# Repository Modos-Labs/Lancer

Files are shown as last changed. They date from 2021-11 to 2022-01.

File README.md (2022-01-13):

Lancer is the codename of our EPD laptop prototype.

# Specifications

The specification listed are preliminary and subject to change.

- SoC: Amlogic S922X (4x Cortex-A73 @ 2.2 GHz + 2x Cortex-A53 @ 2.0 GHz)
- RAM: 4GB DDR4 32bit
- SSD: User-replaceable M.2 SSD
- Network: 802.11n + BT4.0
- Screen: 13.3" 1600x1200 E-paper display via Caster EPDC (over MIPI DSI)
- Battery: Compatible with T4x battery
- Ports:
  - USB 2.0 Type-A Host x2
  - USB 2.0 Micro-B Device
  - USB Serial (Micro-B)
  - 10/100Mbps Ethernet
  - 3.5 mm Headphone Jack
  - 3.5 mm Line-In Jack
  - HDMI Output

# License

The hardware design is released under the CERN Open Source Hardware License strongly-reciprocal variant, CERN-OHL-S. A copy of the license is provided in the source repository. Additionally, user guide of the license is provided on ohwr.org.

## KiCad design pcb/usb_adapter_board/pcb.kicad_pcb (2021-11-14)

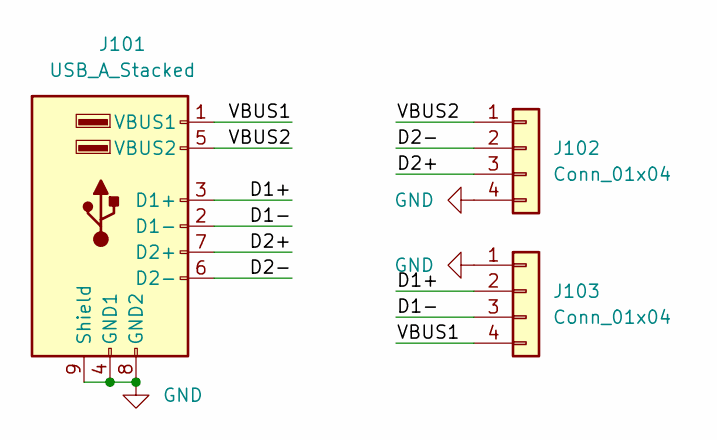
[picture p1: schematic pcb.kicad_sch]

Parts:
J101: USB_A_Stacked; USB_A_Wuerth_614008235023_Vertical_Stacked
J102, J103: Conn_01x04; PinHeader_1x04_P1.27mm_Horizontal_Alt

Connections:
/D1+: J101.3 (D1+), J103.2
/D1-: J101.2 (D1-), J103.3
/D2+: J101.7 (D2+), J102.3
/D2-: J101.6 (D2-), J102.2
/VBUS1: J101.1 (VBUS1), J103.4
/VBUS2: J101.5 (VBUS2), J102.1
GND: J101.4 (GND1), J101.8 (GND2), J101.9 (Shield), J102.4, J103.1

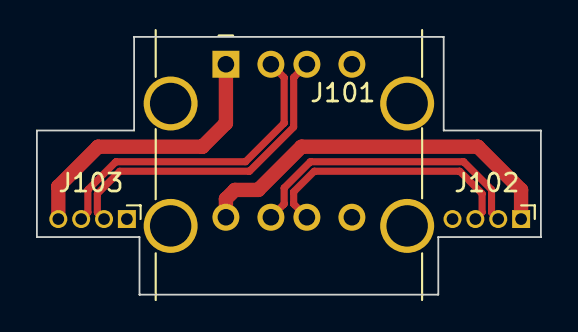
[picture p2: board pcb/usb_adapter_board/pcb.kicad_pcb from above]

Board: 2 copper layers, 28.0 x 14.3 mm, 3 parts (0 on the bottom side), 7 nets.

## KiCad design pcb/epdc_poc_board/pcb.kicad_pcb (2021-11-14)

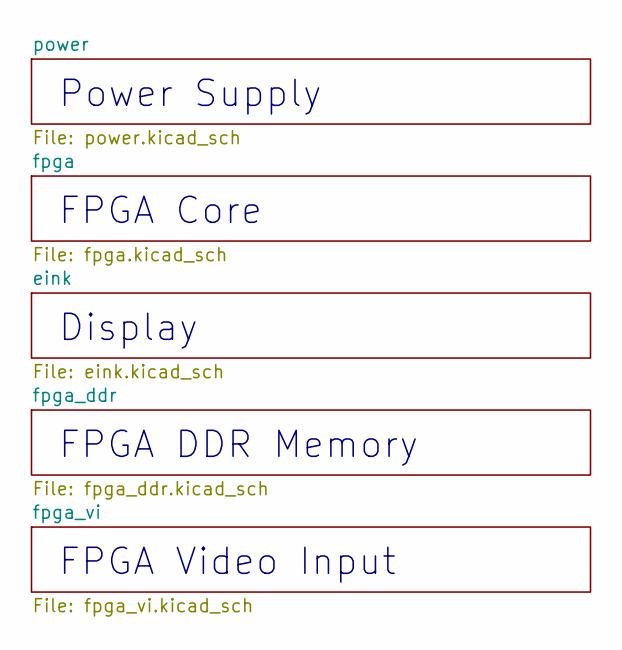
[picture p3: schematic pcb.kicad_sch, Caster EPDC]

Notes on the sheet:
Power Supply
FPGA Core
Display
FPGA DDR Memory
FPGA Video Input

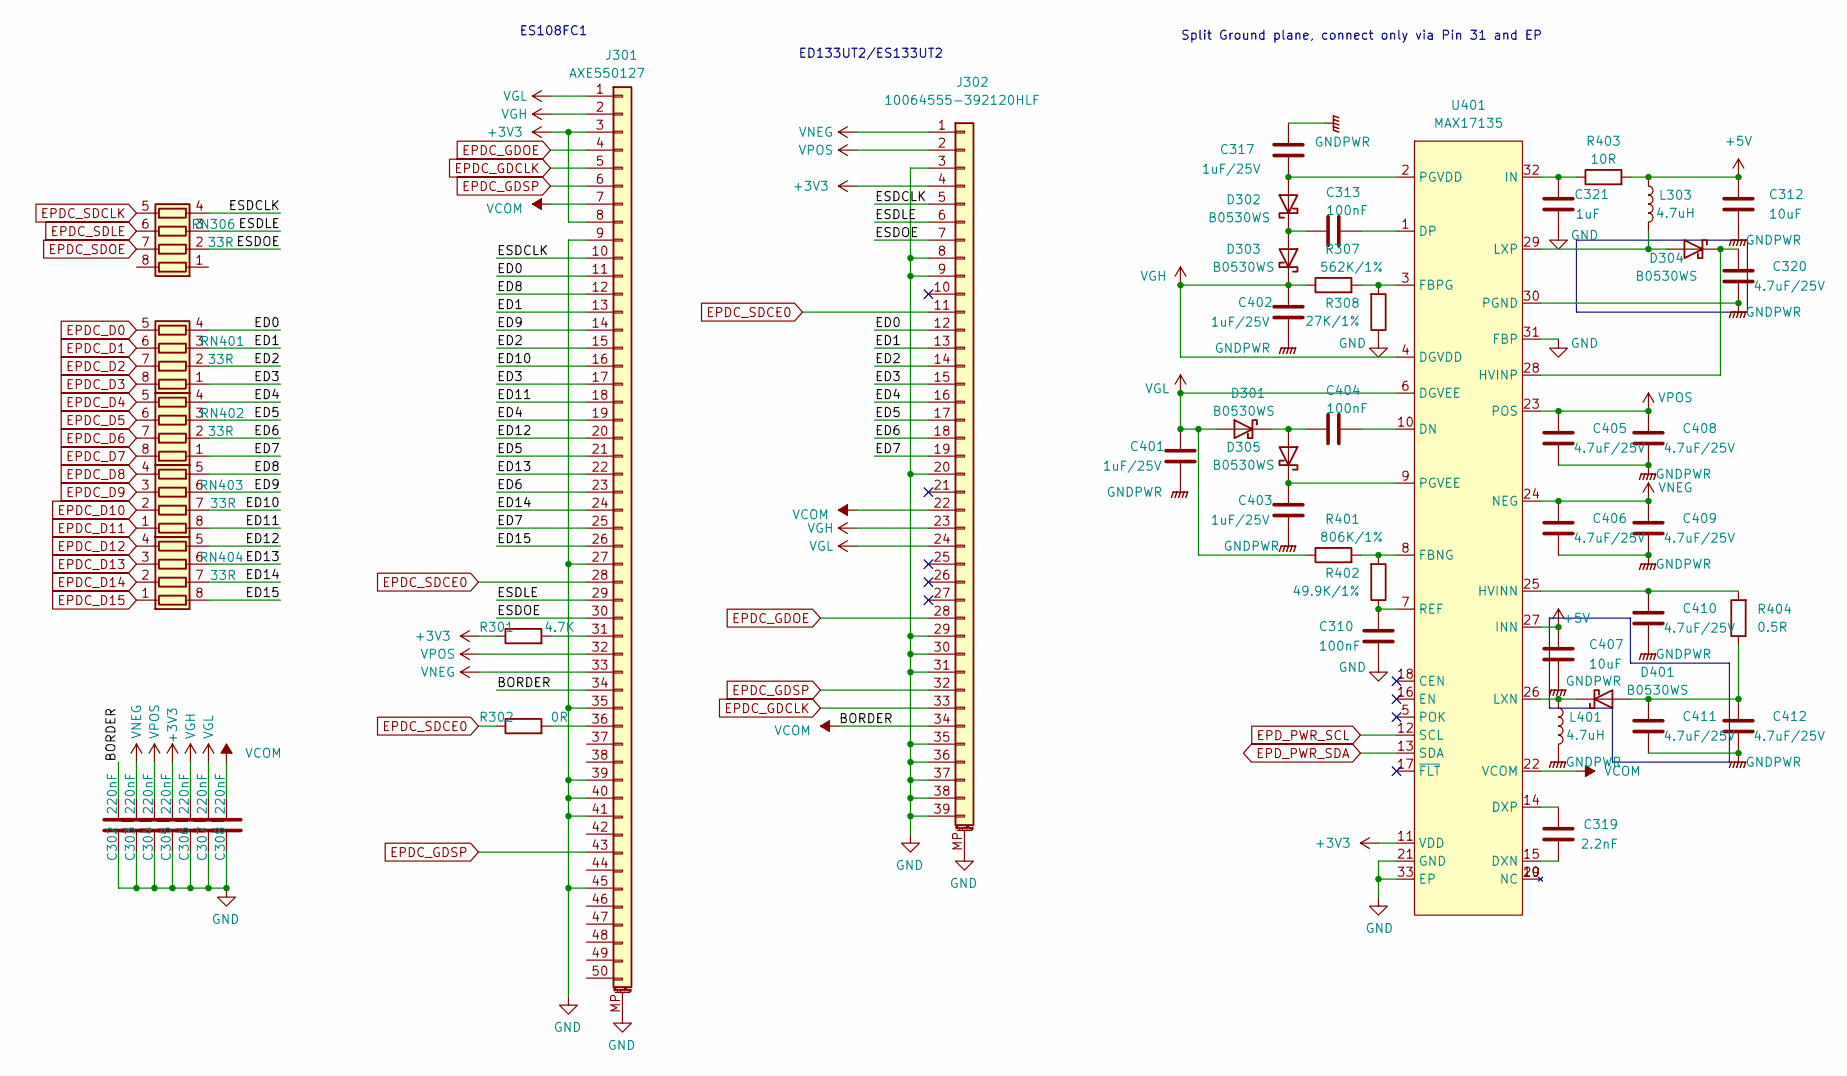
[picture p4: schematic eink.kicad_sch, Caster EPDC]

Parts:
C302, C303, C304, C305, C306, C307, C308: 220nF; C_0402_1005Metric; LCSC C880414
C310, C313, C404: 100nF; C_0402_1005Metric; LCSC C56392
C312, C407: 10uF; C_0603_1608Metric; LCSC C105490
C317, C401, C402, C403: 1uF/25V; C_0805_2012Metric; LCSC C111769
C319: 2.2nF; C_0402_1005Metric; LCSC C913886
C320, C405, C406, C408, C409, C410, C411, C412: 4.7uF/25V; C_0805_2012Metric; LCSC C105489
C321: 1uF; C_0402_1005Metric; LCSC C157353
D301, D302, D303, D304, D305, D401: B0530WS; D_SOD-323; LCSC C475612
J301: AXE550127
J302: 10064555-392120HLF; FCI_10064555-392120HLF; LCSC 609-10064555-392120HLFCT-ND
L303, L401: 4.7uH; L_1212; LCSC C340379
R301: 4.7K; R_0402_1005Metric; LCSC C105870
R302: 0R; R_0402_1005Metric; LCSC C60485
R307: 562K/1%; R_0402_1005Metric; LCSC C273337
R308: 27K/1%; R_0402_1005Metric; LCSC C138022
R401: 806K/1%; R_0402_1005Metric; LCSC C375495
R402: 49.9K/1%; R_0402_1005Metric; LCSC C137969
R403: 10R; R_0402_1005Metric; LCSC C137925
R404: 0.5R; R_0603_1608Metric; LCSC C45312
RN306, RN401, RN402, RN403, RN404: 33R; R_Array_Convex_4x0402; LCSC C148513
U401: MAX17135; QFN-32-1EP_5x5mm_P0.5mm_EP3.1x3.1mm_ThermalVias

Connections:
+3V3: C305.1, J301.3, J301.8, J302.4, R301.1, U401.11 (VDD); also elsewhere on the board
+5V: C312.2, C407.2, L303.1, R403.2, U401.27 (INN); also elsewhere on the board
/eink/ED0: J301.11, J302.12, RN401.4 (R4.1)
/eink/ED1: J301.13, J302.13, RN401.3 (R3.1)
/eink/ED2: J301.15, J302.14, RN401.2 (R2.1)
/eink/ED3: J301.17, J302.15, RN401.1 (R1.1)
/eink/ED4: J301.19, J302.16, RN402.4 (R4.1)
/eink/ED5: J301.21, J302.17, RN402.3 (R3.1)
/eink/ED6: J301.23, J302.18, RN402.2 (R2.1)
/eink/ED7: J301.25, J302.19, RN402.1 (R1.1)
/eink/ED8: J301.12, RN403.5 (R4.2)
/eink/ED9: J301.14, RN403.6 (R3.2)
/eink/ED10: J301.16, RN403.7 (R2.2)
/eink/ED11: J301.18, RN403.8 (R1.2)
/eink/ED12: J301.20, RN404.5 (R4.2)
/eink/ED13: J301.22, RN404.6 (R3.2)
/eink/ED14: J301.24, RN404.7 (R2.2)
/eink/ED15: J301.26, RN404.8 (R1.2)
/eink/ESDCLK: J301.10, J302.5, RN306.4 (R4.1)
/eink/ESDLE: J301.29, J302.6, RN306.3 (R3.1)
/eink/ESDOE: J301.30, J302.7, RN306.2 (R2.1)
EPDC_D0: RN401.5 (R4.2); also elsewhere on the board
EPDC_D1: RN401.6 (R3.2); also elsewhere on the board
EPDC_D2: RN401.7 (R2.2); also elsewhere on the board
EPDC_D3: RN401.8 (R1.2); also elsewhere on the board
EPDC_D4: RN402.5 (R4.2); also elsewhere on the board
EPDC_D5: RN402.6 (R3.2); also elsewhere on the board
EPDC_D6: RN402.7 (R2.2); also elsewhere on the board
EPDC_D7: RN402.8 (R1.2); also elsewhere on the board
EPDC_D8: RN403.4 (R4.1); also elsewhere on the board
EPDC_D9: RN403.3 (R3.1); also elsewhere on the board
EPDC_D10: RN403.2 (R2.1); also elsewhere on the board
EPDC_D11: RN403.1 (R1.1); also elsewhere on the board
EPDC_D12: RN404.4 (R4.1); also elsewhere on the board
EPDC_D13: RN404.3 (R3.1); also elsewhere on the board
EPDC_D14: RN404.2 (R2.1); also elsewhere on the board
EPDC_D15: RN404.1 (R1.1); also elsewhere on the board
EPDC_GDCLK: J301.5, J302.33; also elsewhere on the board
EPDC_GDOE: J301.4, J302.28; also elsewhere on the board
EPDC_GDSP: J301.6, J301.43, J302.32; also elsewhere on the board
EPDC_SDCE0: J301.28, J302.11, R302.1; also elsewhere on the board
EPDC_SDCLK: RN306.5 (R4.2); also elsewhere on the board
EPDC_SDLE: RN306.6 (R3.2); also elsewhere on the board
EPDC_SDOE: RN306.7 (R2.2); also elsewhere on the board
EPD_PWR_SCL: U401.12 (SCL); also elsewhere on the board
EPD_PWR_SDA: U401.13 (SDA); also elsewhere on the board
GND: C302.2, C303.2, C304.2, C305.2, C306.2, C307.2, C308.2, C310.1, C321.1, J301.9, J301.27, J301.35, J301.39, J301.40, J301.41, J301.45, J301.MP (MountPin), J302.3, J302.8, J302.9, J302.20, J302.29, J302.30, J302.31, J302.35, J302.36, J302.37, J302.38, J302.39, J302.MP (MountPin), R308.1, U401.21 (GND), U401.31 (FBP), U401.33 (EP); also elsewhere on the board
GNDPWR: C312.1, C317.2, C320.1, C401.1, C402.1, C403.1, C405.1, C406.1, C407.1, C408.1, C409.1, C410.1, C411.1, C412.1, L401.2, U401.30 (PGND)
unnamed: C310.2, R402.1, U401.7 (REF)
unnamed: C313.1, D302.1 (K), D303.2 (A)
unnamed: C313.2, U401.1 (DP)
unnamed: C317.1, D302.2 (A), U401.2 (PGVDD)
unnamed: C319.1, U401.15 (DXN)
unnamed: C319.2, U401.14 (DXP)
unnamed: C320.2, D304.1 (K), U401.28 (HVINP)
unnamed: C321.2, R403.1, U401.32 (IN)
unnamed: C403.2, D305.1 (K), U401.9 (PGVEE)
unnamed: C404.1, D301.1 (K), D305.2 (A)
unnamed: C404.2, U401.10 (DN)
unnamed: C410.2, R404.2, U401.25 (HVINN)
unnamed: C411.2, C412.2, D401.2 (A), R404.1
unnamed: D304.2 (A), L303.2, U401.29 (LXP)
unnamed: D401.1 (K), L401.1, U401.26 (LXN)
unnamed: J301.31, R301.2
unnamed: J301.36, R302.2
unnamed: R307.2, R308.2, U401.3 (FBPG)
unnamed: R401.2, R402.2, U401.8 (FBNG)
VCOM: C302.1, C308.1, J301.7, J301.34, J302.22, J302.34, U401.22 (VCOM)
VGH: C306.1, C402.2, D303.1 (K), J301.2, J302.23, R307.1, U401.4 (DGVDD)
VGL: C307.1, C401.2, D301.2 (A), J301.1, J302.24, R401.1, U401.6 (DGVEE)
VNEG: C303.1, C406.2, C409.2, J301.33, J302.1, U401.24 (NEG)
VPOS: C304.1, C405.2, C408.2, J301.32, J302.2, U401.23 (POS)

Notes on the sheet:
ES108FC1
ED133UT2/ES133UT2
Split Ground plane, connect only via Pin 31 and EP

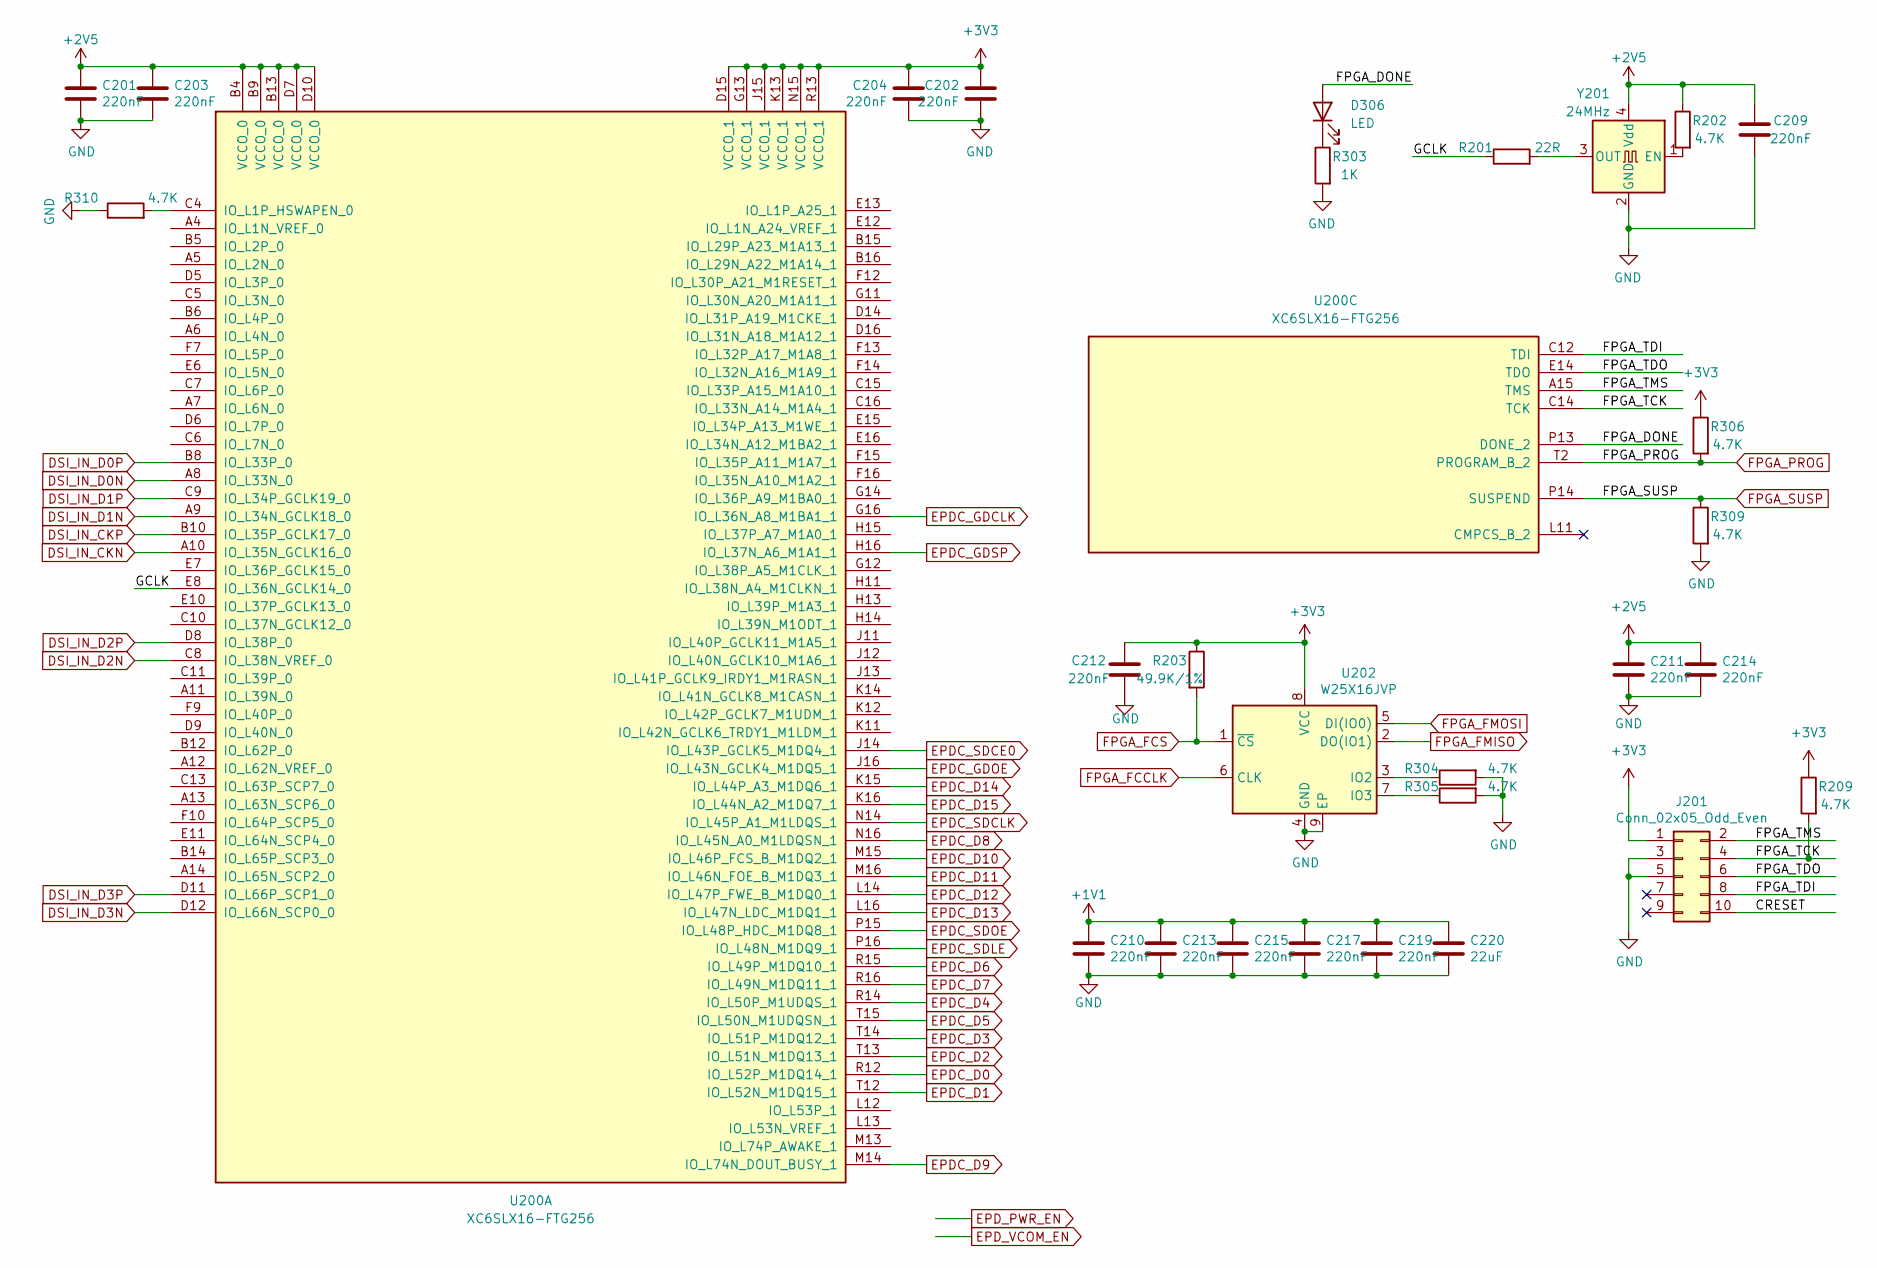
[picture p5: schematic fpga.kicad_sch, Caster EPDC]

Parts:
C201, C202, C203, C204, C209, C210, C211, C212, C213, C214, C215, C217, C219: 220nF; C_0402_1005Metric; LCSC C880414
C220: 22uF; C_0603_1608Metric; LCSC C94018
D306: LED; LED_0603_1608Metric; LCSC C90692
J201: Conn_02x05_Odd_Even; PinHeader_2x05_P1.27mm_Vertical_SMD
R201: 22R; R_0402_1005Metric; LCSC C93929
R202, R209, R304, R305, R306, R309, R310: 4.7K; R_0402_1005Metric; LCSC C105870
R203: 49.9K/1%; R_0402_1005Metric; LCSC C137969
R303: 1K; R_0402_1005Metric; LCSC C105637
U200: XC6SLX16-FTG256; BGA-256_14.0x14.0mm_Layout16x16_P0.8mm_Ball0.45mm_Pad0.32mm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; LCSC C39313
U202: W25X16JVP; WSON-8-1EP_6x5mm_P1.27mm_EP3.4x4.3mm; LCSC C571260
Y201: 24MHz; Oscillator_SMD_Abracon_ASE-4Pin_3.2x2.5mm; LCSC C252339

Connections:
+1V1: C210.1, C213.1, C215.1, C217.1, C219.1, C220.1; also elsewhere on the board
+2V5: C201.1, C203.1, C209.2, C211.1, C214.1, R202.1, U200.B4 (VCCO_0), U200.B9 (VCCO_0), U200.B13 (VCCO_0), U200.D7 (VCCO_0), U200.D10 (VCCO_0), Y201.4 (Vdd); also elsewhere on the board
+3V3: C202.1, C204.1, C212.2, J201.1, R203.1, R209.1, R306.1, U200.D15 (VCCO_1), U200.G13 (VCCO_1), U200.J15 (VCCO_1), U200.K13 (VCCO_1), U200.N15 (VCCO_1), U200.R13 (VCCO_1), U202.8 (VCC); also elsewhere on the board
/fpga/CRESET: J201.10
/fpga/FPGA_DONE: D306.2 (A), U200.P13 (DONE_2)
/fpga/FPGA_TCK: J201.4, R209.2, U200.C14 (TCK)
/fpga/FPGA_TDI: J201.8, U200.C12 (TDI)
/fpga/FPGA_TDO: J201.6, U200.E14 (TDO)
/fpga/FPGA_TMS: J201.2, U200.A15 (TMS)
/fpga/GCLK: R201.1, U200.E8 (IO_L36N_GCLK14_0)
DSI_IN_CKN: U200.A10 (IO_L35N_GCLK16_0); also elsewhere on the board
DSI_IN_CKP: U200.B10 (IO_L35P_GCLK17_0); also elsewhere on the board
DSI_IN_D0N: U200.A8 (IO_L33N_0); also elsewhere on the board
DSI_IN_D0P: U200.B8 (IO_L33P_0); also elsewhere on the board
DSI_IN_D1N: U200.A9 (IO_L34N_GCLK18_0); also elsewhere on the board
DSI_IN_D1P: U200.C9 (IO_L34P_GCLK19_0); also elsewhere on the board
DSI_IN_D2N: U200.C8 (IO_L38N_VREF_0); also elsewhere on the board
DSI_IN_D2P: U200.D8 (IO_L38P_0); also elsewhere on the board
DSI_IN_D3N: U200.D12 (IO_L66N_SCP0_0); also elsewhere on the board
DSI_IN_D3P: U200.D11 (IO_L66P_SCP1_0); also elsewhere on the board
EPDC_D0: U200.R12 (IO_L52P_M1DQ14_1); also elsewhere on the board
EPDC_D1: U200.T12 (IO_L52N_M1DQ15_1); also elsewhere on the board
EPDC_D2: U200.T13 (IO_L51N_M1DQ13_1); also elsewhere on the board
EPDC_D3: U200.T14 (IO_L51P_M1DQ12_1); also elsewhere on the board
EPDC_D4: U200.R14 (IO_L50P_M1UDQS_1); also elsewhere on the board
EPDC_D5: U200.T15 (IO_L50N_M1UDQSN_1); also elsewhere on the board
EPDC_D6: U200.R15 (IO_L49P_M1DQ10_1); also elsewhere on the board
EPDC_D7: U200.R16 (IO_L49N_M1DQ11_1); also elsewhere on the board
EPDC_D8: U200.N16 (IO_L45N_A0_M1LDQSN_1); also elsewhere on the board
EPDC_D9: U200.M14 (IO_L74N_DOUT_BUSY_1); also elsewhere on the board
EPDC_D10: U200.M15 (IO_L46P_FCS_B_M1DQ2_1); also elsewhere on the board
EPDC_D11: U200.M16 (IO_L46N_FOE_B_M1DQ3_1); also elsewhere on the board
EPDC_D12: U200.L14 (IO_L47P_FWE_B_M1DQ0_1); also elsewhere on the board
EPDC_D13: U200.L16 (IO_L47N_LDC_M1DQ1_1); also elsewhere on the board
EPDC_D14: U200.K15 (IO_L44P_A3_M1DQ6_1); also elsewhere on the board
EPDC_D15: U200.K16 (IO_L44N_A2_M1DQ7_1); also elsewhere on the board
EPDC_GDCLK: U200.G16 (IO_L36N_A8_M1BA1_1); also elsewhere on the board
EPDC_GDOE: U200.J16 (IO_L43N_GCLK4_M1DQ5_1); also elsewhere on the board
EPDC_GDSP: U200.H16 (IO_L37N_A6_M1A1_1); also elsewhere on the board
EPDC_SDCE0: U200.J14 (IO_L43P_GCLK5_M1DQ4_1); also elsewhere on the board
EPDC_SDCLK: U200.N14 (IO_L45P_A1_M1LDQS_1); also elsewhere on the board
EPDC_SDLE: U200.P16 (IO_L48N_M1DQ9_1); also elsewhere on the board
EPDC_SDOE: U200.P15 (IO_L48P_HDC_M1DQ8_1); also elsewhere on the board
FPGA_FCCLK: U202.6 (CLK); also elsewhere on the board
FPGA_FCS: R203.2, U202.1 (~CS); also elsewhere on the board
FPGA_FMISO: U202.2 (DO(IO1)); also elsewhere on the board
FPGA_FMOSI: U202.5 (DI(IO0)); also elsewhere on the board
FPGA_PROG: R306.2, U200.T2 (PROGRAM_B_2); also elsewhere on the board
FPGA_SUSP: R309.1, U200.P14 (SUSPEND); also elsewhere on the board
GND: C201.2, C202.2, C203.2, C204.2, C209.1, C210.2, C211.2, C212.1, C213.2, C214.2, C215.2, C217.2, C219.2, C220.2, J201.3, J201.5, R303.2, R304.2, R305.2, R309.2, R310.1, U202.4 (GND), U202.9 (EP), Y201.2 (GND); also elsewhere on the board
unnamed: D306.1 (K), R303.1
unnamed: R201.2, Y201.3 (OUT)
unnamed: R202.2, Y201.1 (EN)
unnamed: R304.1, U202.3 (IO2)
unnamed: R305.1, U202.7 (IO3)
unnamed: R310.2, U200.C4 (IO_L1P_HSWAPEN_0)

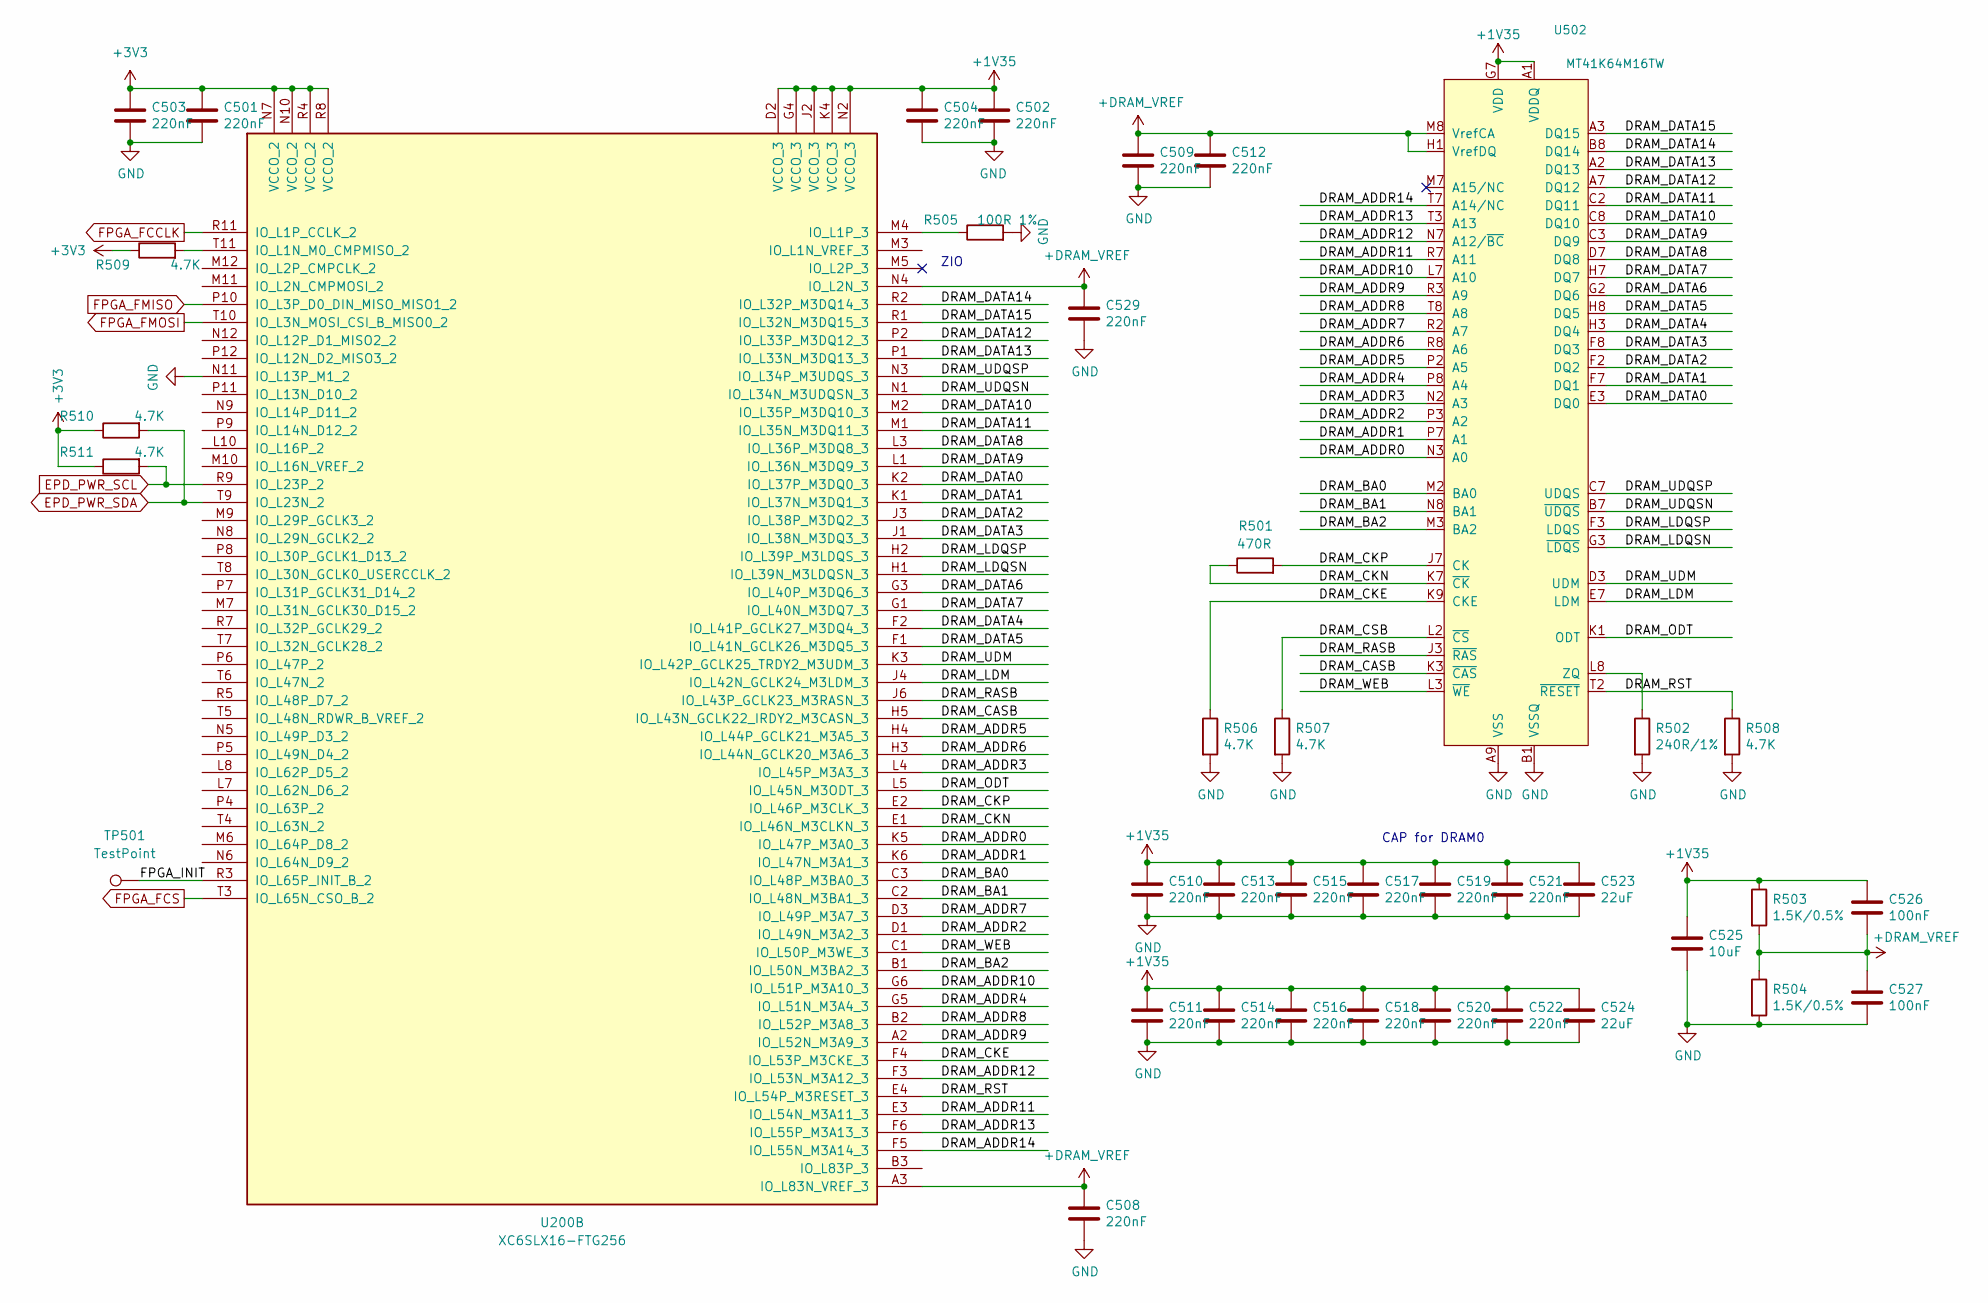
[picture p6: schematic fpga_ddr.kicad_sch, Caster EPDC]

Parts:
C501, C502, C503, C504, C508, C509, C510, C511, C512, C513, C514, C515, C516, C517, C518, C519, C520, C521, C522, C529: 220nF; C_0402_1005Metric; LCSC C880414
C523, C524: 22uF; C_0603_1608Metric; LCSC C94018
C525: 10uF; C_0603_1608Metric; LCSC C105490
C526, C527: 100nF; C_0402_1005Metric; LCSC C56392
R501: 470R; R_0402_1005Metric; LCSC C114877
R502: 240R/1%; R_0402_1005Metric; LCSC C114755
R503, R504: 1.5K/0.5%; R_0402_1005Metric; LCSC C226693
R505: 100R 1%; R_0402_1005Metric; LCSC C106232
R506, R507, R508, R509, R510, R511: 4.7K; R_0402_1005Metric; LCSC C105870
TP501: TestPoint; TestPoint_Pad_D1.0mm
U200: XC6SLX16-FTG256; BGA-256_14.0x14.0mm_Layout16x16_P0.8mm_Ball0.45mm_Pad0.32mm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; LCSC C39313
U502: MT41K64M16TW; BGA-96_9.0x14.0mm_P0.8mm; LCSC C524855

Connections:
+1V35: C502.1, C504.1, C510.1, C511.1, C513.1, C514.1, C515.1, C516.1, C517.1, C518.1, C519.1, C520.1, C521.1, C522.1, C523.1, C524.1, C525.1, C526.1, R503.1, U200.D2 (VCCO_3), U200.G4 (VCCO_3), U200.J2 (VCCO_3), U200.K4 (VCCO_3), U200.N2 (VCCO_3), U502.A1 (VDDQ), U502.A8 (VDDQ), U502.B2 (VDD), U502.C1 (VDDQ), U502.C9 (VDDQ), U502.D2 (VDDQ), U502.D9 (VDD), U502.E9 (VDDQ), U502.F1 (VDDQ), U502.G7 (VDD), U502.H2 (VDDQ), U502.H9 (VDDQ), U502.K2 (VDD), U502.K8 (VDD), U502.N1 (VDD), U502.N9 (VDD), U502.R1 (VDD), U502.R9 (VDD); also elsewhere on the board
+3V3: C501.1, C503.1, R509.1, R510.1, R511.1, U200.N7 (VCCO_2), U200.N10 (VCCO_2), U200.R4 (VCCO_2), U200.R8 (VCCO_2); also elsewhere on the board
+DRAM_VREF: C508.1, C509.1, C512.1, C526.2, C527.1, C529.1, R503.2, R504.1, U200.A3 (IO_L83N_VREF_3), U200.N4 (IO_L2N_3), U502.H1 (VrefDQ), U502.M8 (VrefCA)
/fpga_ddr/DRAM_ADDR0: U200.K5 (IO_L47P_M3A0_3), U502.N3 (A0)
/fpga_ddr/DRAM_ADDR1: U200.K6 (IO_L47N_M3A1_3), U502.P7 (A1)
/fpga_ddr/DRAM_ADDR2: U200.D1 (IO_L49N_M3A2_3), U502.P3 (A2)
/fpga_ddr/DRAM_ADDR3: U200.L4 (IO_L45P_M3A3_3), U502.N2 (A3)
/fpga_ddr/DRAM_ADDR4: U200.G5 (IO_L51N_M3A4_3), U502.P8 (A4)
/fpga_ddr/DRAM_ADDR5: U200.H4 (IO_L44P_GCLK21_M3A5_3), U502.P2 (A5)
/fpga_ddr/DRAM_ADDR6: U200.H3 (IO_L44N_GCLK20_M3A6_3), U502.R8 (A6)
/fpga_ddr/DRAM_ADDR7: U200.D3 (IO_L49P_M3A7_3), U502.R2 (A7)
/fpga_ddr/DRAM_ADDR8: U200.B2 (IO_L52P_M3A8_3), U502.T8 (A8)
/fpga_ddr/DRAM_ADDR9: U200.A2 (IO_L52N_M3A9_3), U502.R3 (A9)
/fpga_ddr/DRAM_ADDR10: U200.G6 (IO_L51P_M3A10_3), U502.L7 (A10)
/fpga_ddr/DRAM_ADDR11: U200.E3 (IO_L54N_M3A11_3), U502.R7 (A11)
/fpga_ddr/DRAM_ADDR12: U200.F3 (IO_L53N_M3A12_3), U502.N7 (A12/~BC)
/fpga_ddr/DRAM_ADDR13: U200.F6 (IO_L55P_M3A13_3), U502.T3 (A13)
/fpga_ddr/DRAM_ADDR14: U200.F5 (IO_L55N_M3A14_3), U502.T7 (A14/NC)
/fpga_ddr/DRAM_BA0: U200.C3 (IO_L48P_M3BA0_3), U502.M2 (BA0)
/fpga_ddr/DRAM_BA1: U200.C2 (IO_L48N_M3BA1_3), U502.N8 (BA1)
/fpga_ddr/DRAM_BA2: U200.B1 (IO_L50N_M3BA2_3), U502.M3 (BA2)
/fpga_ddr/DRAM_CASB: U200.H5 (IO_L43N_GCLK22_IRDY2_M3CASN_3), U502.K3 (~CAS)
/fpga_ddr/DRAM_CKE: R506.1, U200.F4 (IO_L53P_M3CKE_3), U502.K9 (CKE)
/fpga_ddr/DRAM_CKN: R501.1, U200.E1 (IO_L46N_M3CLKN_3), U502.K7 (~CK)
/fpga_ddr/DRAM_CKP: R501.2, U200.E2 (IO_L46P_M3CLK_3), U502.J7 (CK)
/fpga_ddr/DRAM_CSB: R507.1, U502.L2 (~CS)
/fpga_ddr/DRAM_DATA0: U200.K2 (IO_L37P_M3DQ0_3), U502.E3 (DQ0)
/fpga_ddr/DRAM_DATA1: U200.K1 (IO_L37N_M3DQ1_3), U502.F7 (DQ1)
/fpga_ddr/DRAM_DATA2: U200.J3 (IO_L38P_M3DQ2_3), U502.F2 (DQ2)
/fpga_ddr/DRAM_DATA3: U200.J1 (IO_L38N_M3DQ3_3), U502.F8 (DQ3)
/fpga_ddr/DRAM_DATA4: U200.F2 (IO_L41P_GCLK27_M3DQ4_3), U502.H3 (DQ4)
/fpga_ddr/DRAM_DATA5: U200.F1 (IO_L41N_GCLK26_M3DQ5_3), U502.H8 (DQ5)
/fpga_ddr/DRAM_DATA6: U200.G3 (IO_L40P_M3DQ6_3), U502.G2 (DQ6)
/fpga_ddr/DRAM_DATA7: U200.G1 (IO_L40N_M3DQ7_3), U502.H7 (DQ7)
/fpga_ddr/DRAM_DATA8: U200.L3 (IO_L36P_M3DQ8_3), U502.D7 (DQ8)
/fpga_ddr/DRAM_DATA9: U200.L1 (IO_L36N_M3DQ9_3), U502.C3 (DQ9)
/fpga_ddr/DRAM_DATA10: U200.M2 (IO_L35P_M3DQ10_3), U502.C8 (DQ10)
/fpga_ddr/DRAM_DATA11: U200.M1 (IO_L35N_M3DQ11_3), U502.C2 (DQ11)
/fpga_ddr/DRAM_DATA12: U200.P2 (IO_L33P_M3DQ12_3), U502.A7 (DQ12)
/fpga_ddr/DRAM_DATA13: U200.P1 (IO_L33N_M3DQ13_3), U502.A2 (DQ13)
/fpga_ddr/DRAM_DATA14: U200.R2 (IO_L32P_M3DQ14_3), U502.B8 (DQ14)
/fpga_ddr/DRAM_DATA15: U200.R1 (IO_L32N_M3DQ15_3), U502.A3 (DQ15)
/fpga_ddr/DRAM_LDM: U200.J4 (IO_L42N_GCLK24_M3LDM_3), U502.E7 (LDM)
/fpga_ddr/DRAM_LDQSN: U200.H1 (IO_L39N_M3LDQSN_3), U502.G3 (~LDQS)
/fpga_ddr/DRAM_LDQSP: U200.H2 (IO_L39P_M3LDQS_3), U502.F3 (LDQS)
/fpga_ddr/DRAM_ODT: U200.L5 (IO_L45N_M3ODT_3), U502.K1 (ODT)
/fpga_ddr/DRAM_RASB: U200.J6 (IO_L43P_GCLK23_M3RASN_3), U502.J3 (~RAS)
/fpga_ddr/DRAM_RST: R508.1, U200.E4 (IO_L54P_M3RESET_3), U502.T2 (~RESET)
/fpga_ddr/DRAM_UDM: U200.K3 (IO_L42P_GCLK25_TRDY2_M3UDM_3), U502.D3 (UDM)
/fpga_ddr/DRAM_UDQSN: U200.N1 (IO_L34N_M3UDQSN_3), U502.B7 (~UDQS)
/fpga_ddr/DRAM_UDQSP: U200.N3 (IO_L34P_M3UDQS_3), U502.C7 (UDQS)
/fpga_ddr/DRAM_WEB: U200.C1 (IO_L50P_M3WE_3), U502.L3 (~WE)
/fpga_ddr/FPGA_INIT: TP501.1, U200.R3 (IO_L65P_INIT_B_2)
EPD_PWR_SCL: R511.2, U200.R9 (IO_L23P_2); also elsewhere on the board
EPD_PWR_SDA: R510.2, U200.T9 (IO_L23N_2); also elsewhere on the board
FPGA_FCCLK: U200.R11 (IO_L1P_CCLK_2); also elsewhere on the board
FPGA_FCS: U200.T3 (IO_L65N_CSO_B_2); also elsewhere on the board
FPGA_FMISO: U200.P10 (IO_L3P_D0_DIN_MISO_MISO1_2); also elsewhere on the board
FPGA_FMOSI: U200.T10 (IO_L3N_MOSI_CSI_B_MISO0_2); also elsewhere on the board
GND: C501.2, C502.2, C503.2, C504.2, C508.2, C509.2, C510.2, C511.2, C512.2, C513.2, C514.2, C515.2, C516.2, C517.2, C518.2, C519.2, C520.2, C521.2, C522.2, C523.2, C524.2, C525.2, C527.2, C529.2, R502.2, R504.2, R505.2, R506.2, R507.2, R508.2, U200.N11 (IO_L13P_M1_2), U502.A9 (VSS), U502.B1 (VSSQ), U502.B3 (VSS), U502.B9 (VSSQ), U502.D1 (VSSQ), U502.D8 (VSSQ), U502.E1 (VSS), U502.E2 (VSSQ), U502.E8 (VSSQ), U502.F9 (VSSQ), U502.G1 (VSSQ), U502.G8 (VSS), U502.G9 (VSSQ), U502.J2 (VSS), U502.J8 (VSS), U502.M1 (VSS), U502.M9 (VSS), U502.P1 (VSS), U502.P9 (VSS), U502.T1 (VSS), U502.T9 (VSS); also elsewhere on the board
unnamed: R502.1, U502.L8 (ZQ)
unnamed: R505.1, U200.M4 (IO_L1P_3)
unnamed: R509.2, U200.T11 (IO_L1N_M0_CMPMISO_2)

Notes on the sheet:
ZIO
CAP for DRAM0

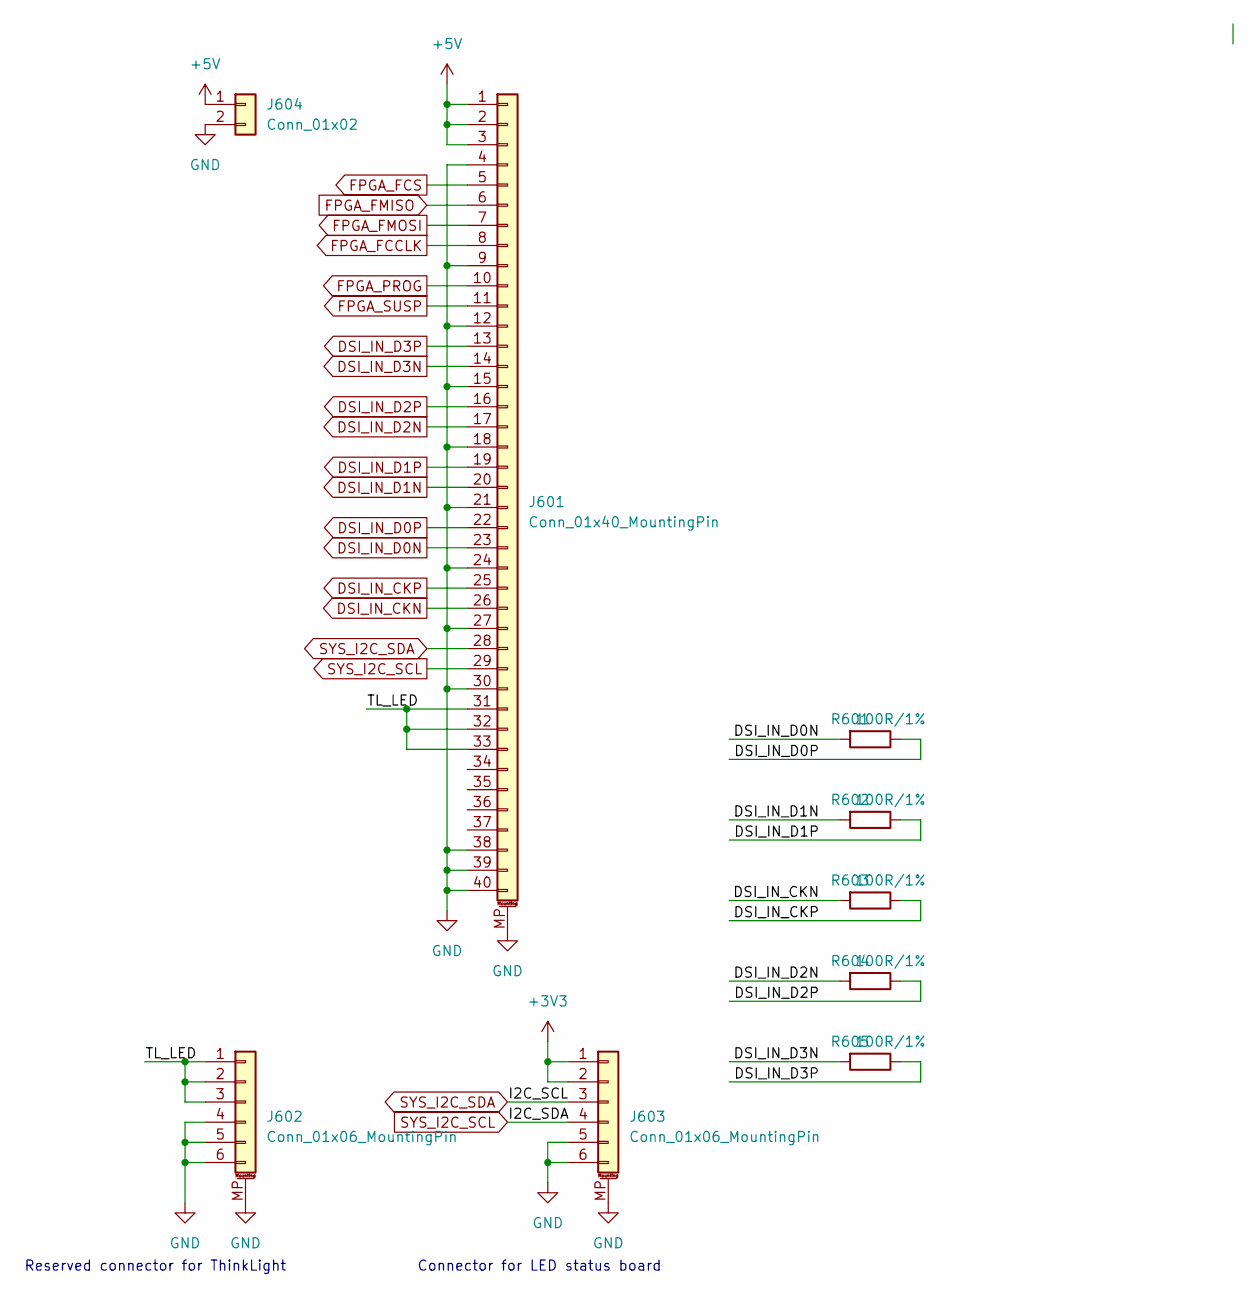
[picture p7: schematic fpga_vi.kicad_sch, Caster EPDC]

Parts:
J601: Conn_01x40_MountingPin; Hirose_FH12-40S-0.5SH_1x40-1MP_P0.50mm_Horizontal; LCSC C376071
J602, J603: Conn_01x06_MountingPin; Hirose_FH12-6S-0.5SH_1x06-1MP_P0.50mm_Horizontal; LCSC C283139
J604: Conn_01x02; PinHeader_1x02_P2.54mm_Vertical
R601, R602, R603, R604, R605: 100R/1%; R_0402_1005Metric; LCSC C106232

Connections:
+3V3: J603.1, J603.2; also elsewhere on the board
+5V: J601.1, J601.2, J601.3, J604.1; also elsewhere on the board
/fpga_vi/TL_LED: J601.31, J601.32, J601.33, J602.1, J602.2, J602.3
DSI_IN_CKN: J601.26, R603.2; also elsewhere on the board
DSI_IN_CKP: J601.25, R603.1; also elsewhere on the board
DSI_IN_D0N: J601.23, R601.2; also elsewhere on the board
DSI_IN_D0P: J601.22, R601.1; also elsewhere on the board
DSI_IN_D1N: J601.20, R602.2; also elsewhere on the board
DSI_IN_D1P: J601.19, R602.1; also elsewhere on the board
DSI_IN_D2N: J601.17, R604.2; also elsewhere on the board
DSI_IN_D2P: J601.16, R604.1; also elsewhere on the board
DSI_IN_D3N: J601.14, R605.2; also elsewhere on the board
DSI_IN_D3P: J601.13, R605.1; also elsewhere on the board
FPGA_FCCLK: J601.8; also elsewhere on the board
FPGA_FCS: J601.5; also elsewhere on the board
FPGA_FMISO: J601.6; also elsewhere on the board
FPGA_FMOSI: J601.7; also elsewhere on the board
FPGA_PROG: J601.10; also elsewhere on the board
FPGA_SUSP: J601.11; also elsewhere on the board
GND: J601.4, J601.9, J601.12, J601.15, J601.18, J601.21, J601.24, J601.27, J601.30, J601.38, J601.39, J601.40, J601.MP (MountPin), J602.4, J602.5, J602.6, J602.MP (MountPin), J603.5, J603.6, J603.MP (MountPin), J604.2; also elsewhere on the board
SYS_I2C_SCL: J601.29, J603.4
SYS_I2C_SDA: J601.28, J603.3

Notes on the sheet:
Reserved connector for ThinkLight
Connector for LED status board

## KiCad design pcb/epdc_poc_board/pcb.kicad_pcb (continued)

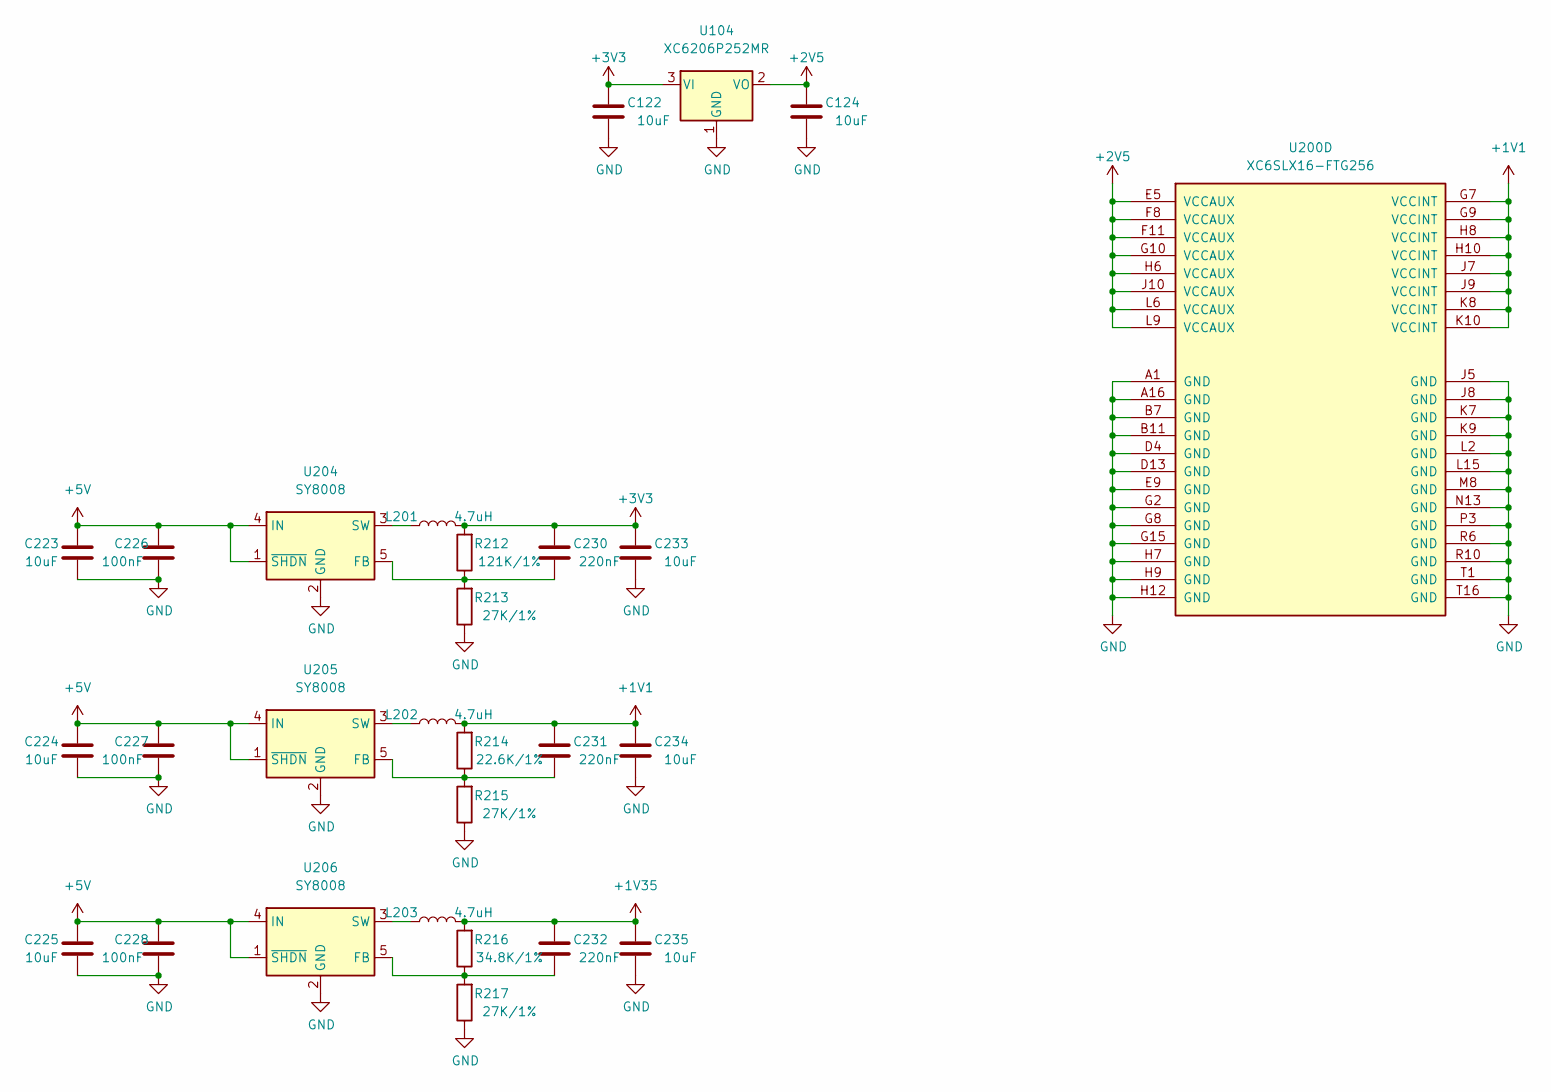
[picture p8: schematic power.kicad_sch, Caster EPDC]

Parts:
C122, C124, C223, C224, C225, C233, C234, C235: 10uF; C_0603_1608Metric; LCSC C105490
C226, C227, C228: 100nF; C_0402_1005Metric; LCSC C56392
C230, C231, C232: 220nF; C_0402_1005Metric; LCSC C880414
L201, L202, L203: 4.7uH; L_1212; LCSC C340379
R212: 121K/1%; R_0402_1005Metric; LCSC C112303
R213, R215, R217: 27K/1%; R_0402_1005Metric; LCSC C138022
R214: 22.6K/1%; R_0402_1005Metric; LCSC C477674
R216: 34.8K/1%; R_0402_1005Metric; LCSC C327350
U104: XC6206P252MR; SOT-23; LCSC C15906
U200: XC6SLX16-FTG256; BGA-256_14.0x14.0mm_Layout16x16_P0.8mm_Ball0.45mm_Pad0.32mm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; LCSC C39313
U204, U205, U206: SY8008; TSOT-23-5; LCSC C82161

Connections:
+1V1: C231.2, C234.2, L202.2, R214.2, U200.G7 (VCCINT), U200.G9 (VCCINT), U200.H8 (VCCINT), U200.H10 (VCCINT), U200.J7 (VCCINT), U200.J9 (VCCINT), U200.K8 (VCCINT), U200.K10 (VCCINT); also elsewhere on the board
+1V35: C232.2, C235.2, L203.2, R216.2; also elsewhere on the board
+2V5: C124.2, U104.2 (VO), U200.E5 (VCCAUX), U200.F8 (VCCAUX), U200.F11 (VCCAUX), U200.G10 (VCCAUX), U200.H6 (VCCAUX), U200.J10 (VCCAUX), U200.L6 (VCCAUX), U200.L9 (VCCAUX); also elsewhere on the board
+3V3: C122.2, C230.2, C233.2, L201.2, R212.2, U104.3 (VI); also elsewhere on the board
+5V: C223.2, C224.2, C225.2, C226.2, C227.2, C228.2, U204.1 (~SHDN), U204.4 (IN), U205.1 (~SHDN), U205.4 (IN), U206.1 (~SHDN), U206.4 (IN); also elsewhere on the board
GND: C122.1, C124.1, C223.1, C224.1, C225.1, C226.1, C227.1, C228.1, C233.1, C234.1, C235.1, R213.1, R215.1, R217.1, U104.1 (GND), U200.A1 (GND), U200.A16 (GND), U200.B7 (GND), U200.B11 (GND), U200.D4 (GND), U200.D13 (GND), U200.E9 (GND), U200.G2 (GND), U200.G8 (GND), U200.G15 (GND), U200.H7 (GND), U200.H9 (GND), U200.H12 (GND), U200.J5 (GND), U200.J8 (GND), U200.K7 (GND), U200.K9 (GND), U200.L2 (GND), U200.L15 (GND), U200.M8 (GND), U200.N13 (GND), U200.P3 (GND), U200.R6 (GND), U200.R10 (GND), U200.T1 (GND), U200.T16 (GND), U204.2 (GND), U205.2 (GND), U206.2 (GND); also elsewhere on the board
unnamed: C230.1, R212.1, R213.2, U204.5 (FB)
unnamed: C231.1, R214.1, R215.2, U205.5 (FB)
unnamed: C232.1, R216.1, R217.2, U206.5 (FB)
unnamed: L201.1, U204.3 (SW)
unnamed: L202.1, U205.3 (SW)
unnamed: L203.1, U206.3 (SW)

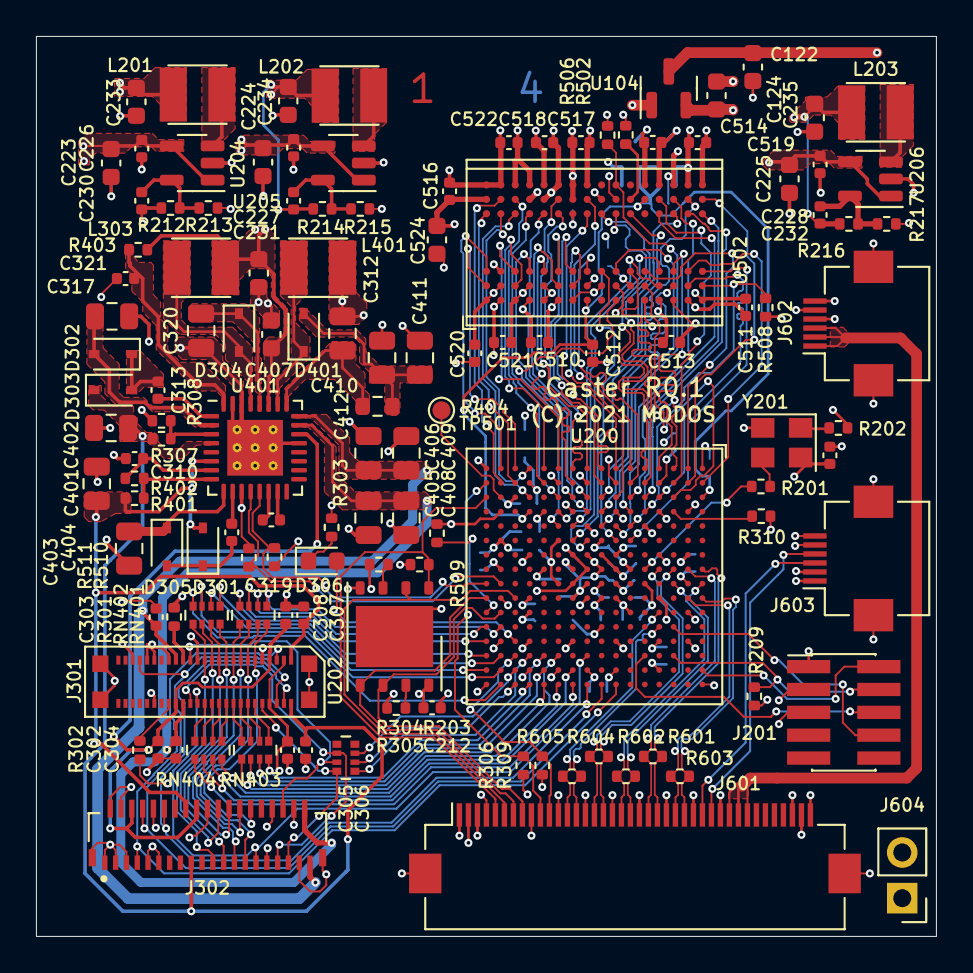
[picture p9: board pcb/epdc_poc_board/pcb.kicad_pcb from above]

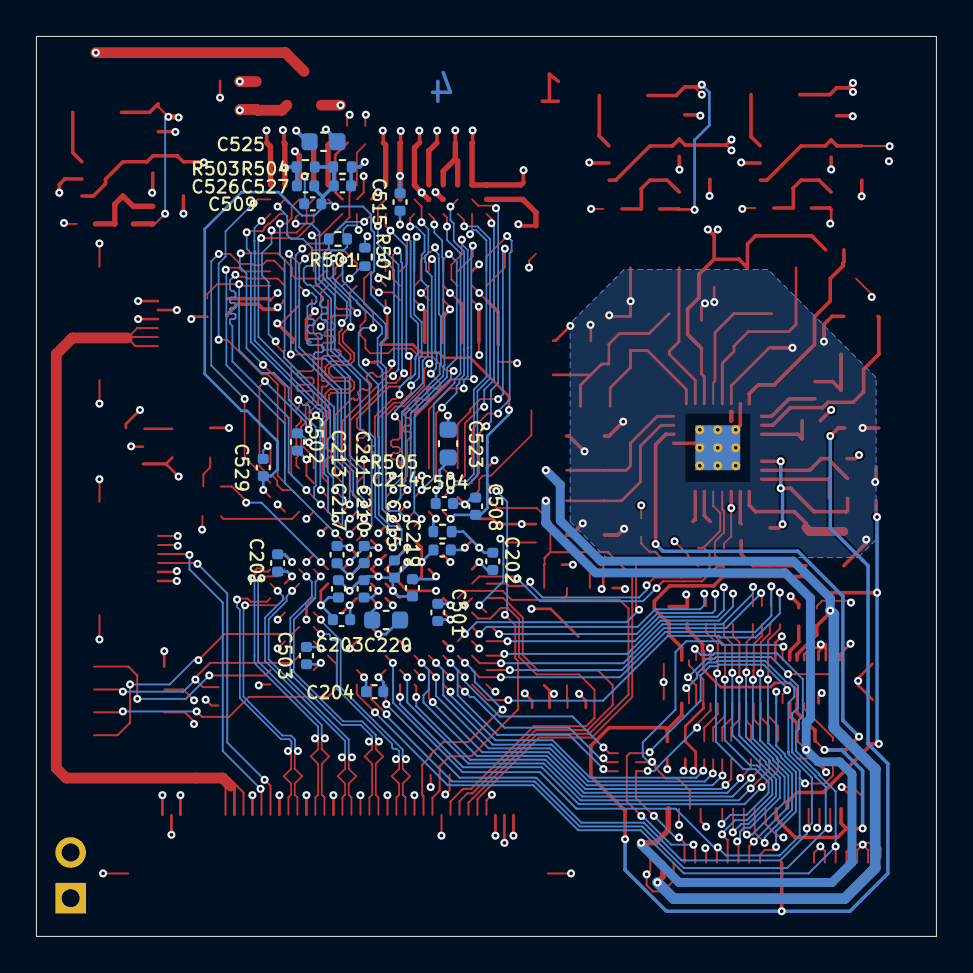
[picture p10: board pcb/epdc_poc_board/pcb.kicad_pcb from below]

Board: 4 copper layers, 50.0 x 50.0 mm, 153 parts (29 on the bottom side), 166 nets.

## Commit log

2021-10-10 pcb: move motherboard to a new directory; working on epdc poc board
    [eink.kicad_sch, fpga.kicad_sch, fpga_ddr.kicad_sch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]
2021-10-17 - wip epdc poc board, going to remove vga input
    [eink.kicad_sch, fpga.kicad_sch, fpga_ddr.kicad_sch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]
2021-10-24 pcb: switch to s6 for epdc board
    [eink.kicad_sch, fpga.kicad_sch, fpga_ddr.kicad_sch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]
2021-10-31 pcb: preliminary r0p1 schematics
    [audio.kicad_sch, cpu.kicad_sch, ddr.kicad_sch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]
2021-11-04 pcb: initial placement for mb
    [audio.kicad_sch, cpu.kicad_sch, ec.kicad_sch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]
2021-11-07 pcb: r0.1 mb routing done
    [audio.kicad_sch, cpu.kicad_sch, ec.kicad_sch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]
2021-11-14 pcb: mb r0.1, caster r0.1 freeze
    [audio.kicad_sch, cpu.kicad_sch, ddr.kicad_sch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]

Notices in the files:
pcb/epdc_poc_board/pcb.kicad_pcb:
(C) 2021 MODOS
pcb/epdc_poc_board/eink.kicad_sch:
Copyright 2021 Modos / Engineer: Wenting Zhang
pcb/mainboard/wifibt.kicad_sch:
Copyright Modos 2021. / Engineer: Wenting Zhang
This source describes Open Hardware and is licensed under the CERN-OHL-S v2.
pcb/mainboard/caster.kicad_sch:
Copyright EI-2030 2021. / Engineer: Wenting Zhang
